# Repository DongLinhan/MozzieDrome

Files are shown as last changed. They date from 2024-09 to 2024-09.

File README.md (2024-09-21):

Details on the MozzieDrome circadian host-seeking assay

For construction, please refer to our preprint https://doi.org/10.1101/2024.09.19.613886

For additional construction details, see "MozzieDrome_construction"

For codes used in operating the MozzieDrome, see "MozzieDrome_operation"

For analysis of mosquito CO2 response, see "MozzieDrome_analysis"

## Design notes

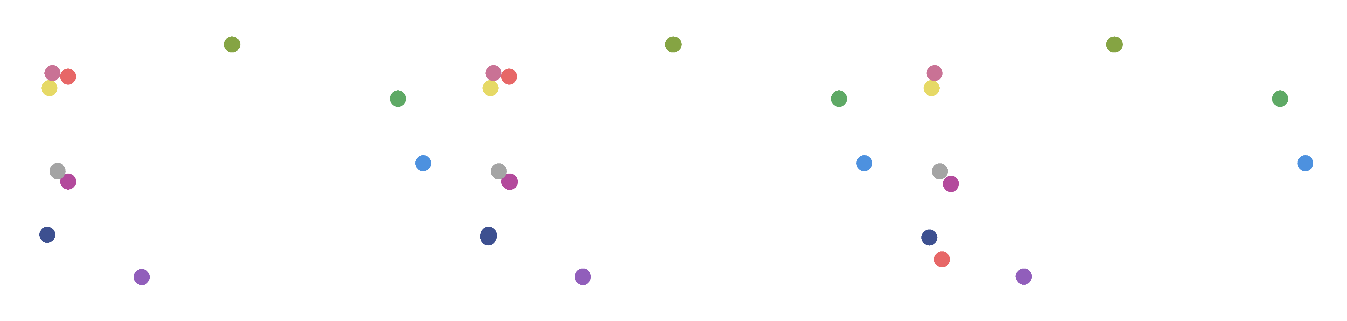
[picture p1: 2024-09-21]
MozzieDrome_analysis/Plotting_outputs/ZT18_new_representative_plots_solidcolors.png

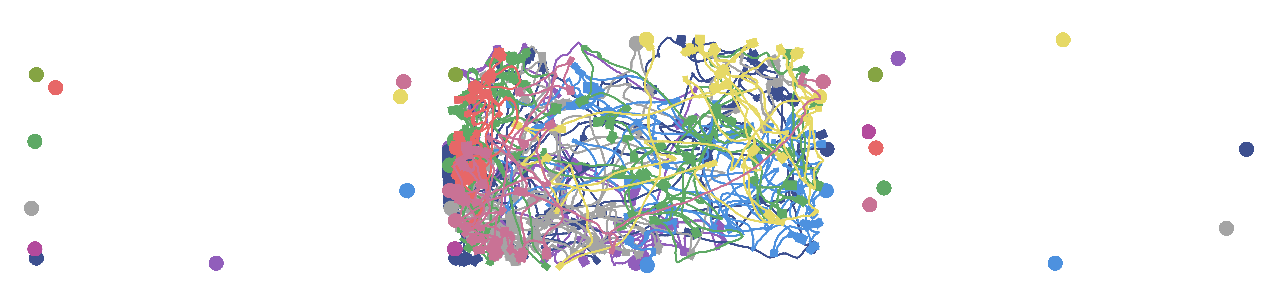
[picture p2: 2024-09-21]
MozzieDrome_analysis/Plotting_outputs/ZT6_new_representative_plots_solidcolors.png

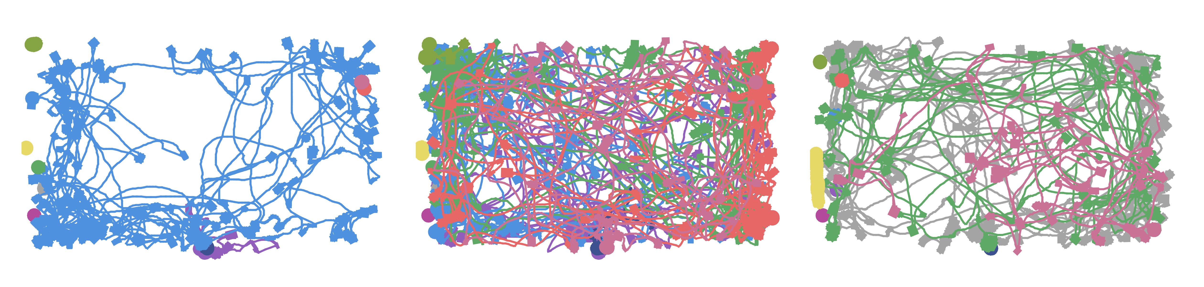
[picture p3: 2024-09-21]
MozzieDrome_analysis/Plotting_outputs/ZT12_new_representative_plots_solidcolors.png

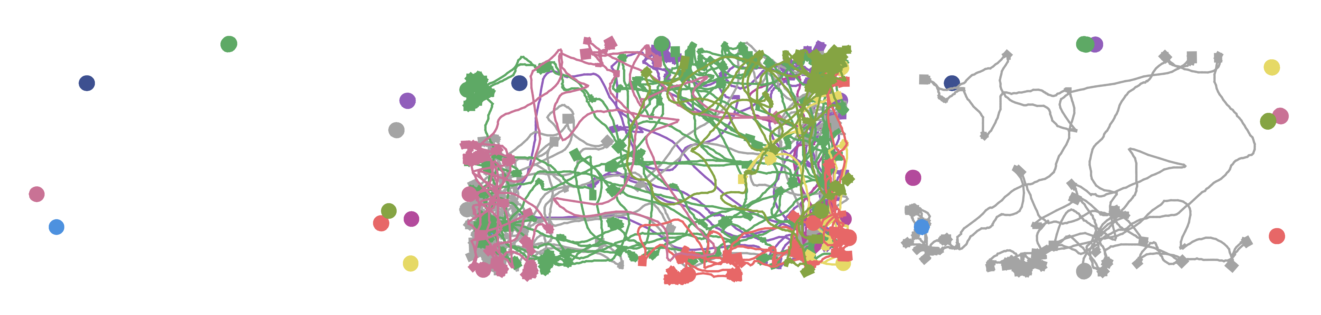
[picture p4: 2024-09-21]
MozzieDrome_analysis/Plotting_outputs/ZT0_new_representative_plots_solidcolors.png

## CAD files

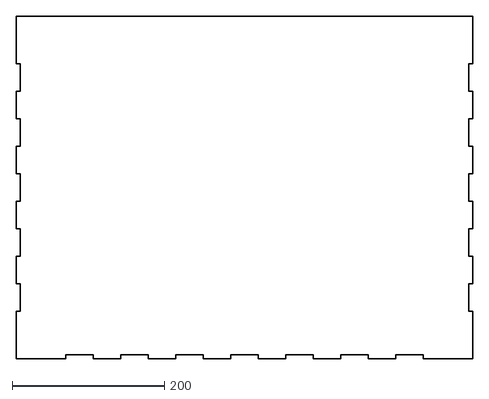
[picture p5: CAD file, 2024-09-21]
MozzieDrome_construction/Laser cutting files/Bottom-side.dxf
600.0 x 450.0

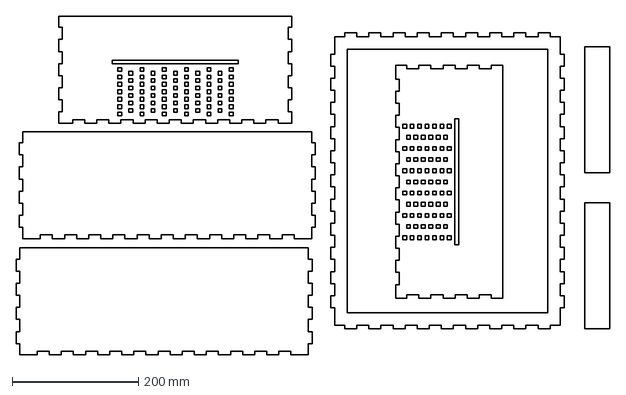
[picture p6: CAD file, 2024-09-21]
MozzieDrome_construction/Laser cutting files/side_light_box_final.dxf
942.5 x 537.6 mm

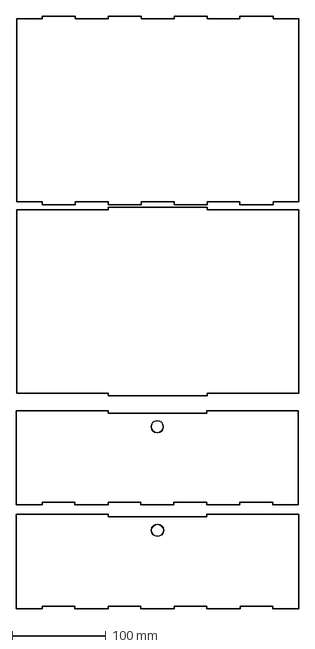
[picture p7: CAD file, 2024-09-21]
MozzieDrome_construction/Laser cutting files/arena_with_sugar_hole.dxf
300.8 x 630.4 mm

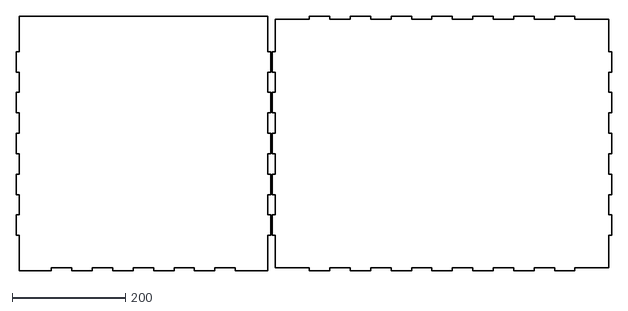
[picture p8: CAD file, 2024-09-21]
MozzieDrome_construction/Laser cutting files/Back-side.dxf
1053.0 x 450.0

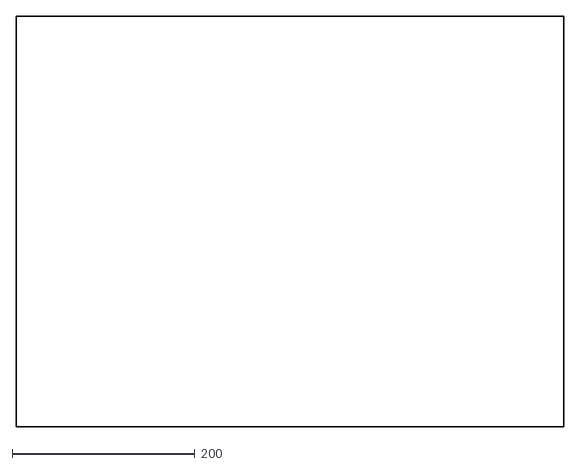
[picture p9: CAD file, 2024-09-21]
MozzieDrome_construction/Laser cutting files/door.dxf
600.0 x 450.0

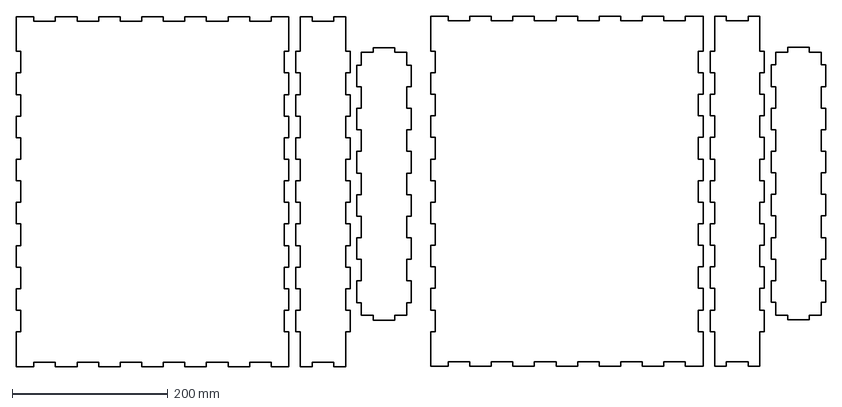
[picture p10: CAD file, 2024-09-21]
MozzieDrome_construction/Laser cutting files/back_light_box_final.dxf
1040.0 x 450.3 mm

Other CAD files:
MozzieDrome_construction/Laser cutting files/sugar_feeder_holder.dxf

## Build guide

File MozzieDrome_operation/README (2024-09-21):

The MozzieDrome assay builds on top of the Rampino system and therefore the folders are named as such for ease of operation. Briefly, the Matlab codes in the “Rampino folder establishes serial communication with an Arduino board equipped with coded in the “RampinoSVR” folder. Parameters can be found directly in the Matlab codes.

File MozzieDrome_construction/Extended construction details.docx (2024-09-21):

Extended construction details:

The MozzieDrome host-seeking assay features a circadian entrainment enclosure, a video-recording platform, a mosquito arena, with CO2 delivery components. Acrylic sheets for all custom-built components were processed with a laser cutter and/or a hand drill.

Circadian entrainment enclosure. The overall enclosure of the MozzieDrome is constructed with 1/4'’ black acrylic sheets. A 60 x 45 x 45 cm open box with ventilations is constructed with five finger edge joints with a 60 x 45 cm open face. The open box is assembled with acrylic cement. A 60 x 45 cm panel is installed with door hinges and latches secured with screw and nuts over holes created with a hand drill. Black foam tape was applied to the rims of the open box and them secured with duct tape. Black-out curtains were installed and used during experiments to completely cover the open door to ensure a tight, light-proof seal. Four rubber feet were sticked on the bottom of the box to provide elevation and soften vibration. The bottom of the box has ventilation holes that is then covered with an elevated black acrylic platform to ensure a complete dark environment. The pre-cut holes on top of the box were equipped with two USB cooling fans secured with hot glue, and then covered with an elevated platform and then another “cap”. The center of the top of the box has hole for camera placement. The lighting system of the MozzieDrome uses white LED strips covered with a 1/8’’ white translucent acrylic sheet to provide diffusion. The diffusion sheet has a pre-cut hole in the middle to allow camera to image through and holes around the edges to avoid blockage of air circulation. The white LED light is controlled together with the CO2 delivery system with a Matlab code to provide animals with LD (12 h light: 12 h dark, with 30 min transitions) and DD entrainments.

Video-recording platform. The video-recording platform features a camera mount that is installed on the camera hole on top of the overall enclosure and an IR light platform that provides illumination for videography. The camera mount was constructed with 1/4'’ black acrylic sheets with finger edge joints and a sliding front door. The bottom of the camera mount is equipped with black foam tape and the camera mount is installed on top of the overall enclosure with screw and nuts over holes created with a hand drill. An IR longpass filter is taped from the inside of the overall enclosure to block visible light from entering the enclosure and prevent visible light interfering with video acquisition. The IR light platform is constructed with 1/4’’ clear acrylic sheets. Backlight IR illumination was provided with a custom-built light box which was constructed with finger edge joints that was secured with acrylic glue. The light box was taped with reflective sheet and installed with strips of 840 nm IR light. On top of the light box, two sheets of Kimwipe were laid to provide diffusion. Surrounding the light box, we constructed a side IR light source with 1/4’’ clear acrylic sheets that was secured with acrylic cement. Mounted around this acrylic frame is 840 nm IR light covered with a white tape to provide diffusion. Both the side and the back lighting are powered with a 12V DC power source and turned on throughout experiments.

Mosquito arena. The mosquito arena was constructed with 1/8’’ clear acrylic sheets. A 10 x 20 x 30 cm rectangular tube (with 10 x 20 cm open faces) was constructed with finger edge joints and secured with acrylic cement. On the 10 x 30 cm sides, two pre-cut holes xx mm in diameter were designed to accommodate sugar feeders. The open faces were covered with mesh sheets that is secured on one 20 cm sides of the rectangular tube with hot glue. Mesh sheets have overhangs that allows them to be taped to the rectangular tubes on the adjacent sides. A stand for sugar feeder was constructed with 1/8’’ clear acrylic sheets and acrylic cement to sit on the rims of the side IR light source.

CO2 delivery system. The CO2 delivery system uses 1/4’’ OD tubings and 1/8’’ ID tubings. A solenoid valves were used to control the flow speed of CO2 by adjusting the duration of an on/off cycle according to readings from a flow meter. Custom mixed 10% CO2 was supplied to the solenoid valve, and the output side of the solenoid that is normally open is sealed with a short 1/4’’ OD tubing with a cap. The CO2 supply flows through the solenoid valve, a pressure-reducing chamber, a digital flowmeter, and a panel-mount flowmeter before entering the overall enclosure. Inside the overall enclosure, a T-spliter was used to divert the CO2 stream into two diffuser pads. The two diffuser pads were secured on the side IR light source.

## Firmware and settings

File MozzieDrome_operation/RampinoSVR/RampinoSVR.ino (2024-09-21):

#define REV "221216.1" 
/* 
 STILL IN DEVELOPMENT DC Motor section no tested yet
 REV 221216.1 adds special pinMode to set PWM frequency
 REV 221208.1 adds I2C support for TCA9548A MUX, STC31 Co2, SHTC3 Humidity, and Sfm3000 sensors, 
 REV 1.2 adds SPI for Adafruit DotStar LED strg Library
 REV 1.1 adds support for stepper limit switch polarity
 
 
 Rampino Server for MATLAB, Rick Hormigo, ZMBBI AIC Columbia university 2021                         
 state machine derived from 2012 arduinoio server by deGiampiero Campa for Matlab    
 This actual code supports current 2021 Arduino Mega board with Ramps 1.6 Plus boards 
 The communication arduinoio protocol has been modifified to minimize overhead
 acelerated to 250000 bauds, and extended to cover the modern stepper and DC motor drivers supported by Ramps  
 
 This server is meant to be used with the MATLAB rampino class. 
 The class is instantiated with a serial communitations port,
 what allows multiple instances as far each uses a separate port and Mega/Ramps combination
 Also it is possible to use a Mega board alone, if no extra electronics are requiered.
 This server can also be used along with other serial terminal softare that follows the protocol

Serial Protocol:
There is a state machine that process several states. The state s is calculated as: s=10*(val-48)
 Where val is what arrives to the serial port in decimal (or ASCII equivalent, a ex. a 88='X'):
 2 to 4 Bytes together are processed, First the mode (or command) where val is decimal 48 to 89,
 such as pinMode or AnalogRead, second the pin we are addresing where val is 99 to 166 depending on the command, 
 and third (if requiered) value for the pin that could be any decimal 0 to 255
 Then some commands can respond with a single byte or two for value.
 
At reset the state machine is s=-1 (idle) state while waits for a valid byte to arrive in the serial port. 
first byte that arrives is used to calculate next state s as s=10*(val-48) 
These are the possible command states:       
s=0  (val=48 or '0')is pinMode
s=10 (val=49 or '1')is digitaRead
s=20 (val=50 or '2')is digitalWrite;  
s=30 (val=51 or '3')is analogRead
s=40 (val=52 or '4')is analogWrite 
s=50 (val=53 or '5')is servoStatus
s=60 (val=54 or '6')is servoAttach and servoDetach 
s=70 (val=55 or '7')is servoRead
s=80 (val=56 or '8')is servoWrite
s=90 (val=57 or '9')is server type. This is Rampino=82 (Ascii 'R')
s=100(val=58 or ':')is tone  
s=110(val=59 or ';')is DCMotorAttach and DCMotorDetach
s=120(val=60 or '<')is DCMotorStatus
s=130(val=61 or '=')is DCMotorVelocity
s=170(val=65 or 'A')is stepperAttach and stepperDetach
s=180(val=66 or 'B')is stepperStatus
s=190(val=67 or 'C')is stepperSpeed
s=200(val=68 or 'D')is stepperStep
s=210(val=69 or 'E')is encoderAttach
s=220(val=70 or 'F')is encoderDetach
s=230(val=71 or 'G')is encoderRead
s=240(val=72 or 'H')is encoderReset
s=250(val=73 or 'I')is encoderDebounce
s=270(val=75 or 'K')is SPI serialLEDs (DotStar)
s=290(val=77 or 'M')is I2C Mux and Multiple sensors 
s=340(val=82 or 'R')is analogReference
s=400(val=88 or 'X')is roundTrip

Next (for most commands) the pin value is read as val=99 to 166 or ascii 'c' to 'ª'
to what is subtacted 97 to calculate the pin=2 to 69 (Mega pins)

Depending on the command there can be other additional states involving byte values need for execution
(see below individual commands)

A simple example to set pin 13 in output mode... 48-110-49 (in decimal sending) or "0n1" no quotations nor CR LF values used (ASCII string).

Mega harware resources used by rampino:
Serial0: Protocol interface
Timer0: Timing: delay(), millis, and micros(). AnalogWrite at pins 4 and 23 (Mega)
Timer1: 16bit used by Servo lib pins 2 to 11. AnalogWrite at pins 11 and 12 (Mega)
Timer2: DC Motor PWM at Any Pin library (DCM_PWM_AP). AnalogWrite at pins 9 and 10 (Mega)
Timer3: Tones (3rd instance) AnalogWrite at pins 2, 3, and 5 (Mega)
Timer4: Tones (2nd instance) AnalogWrite at pins 6, 7, and 8 (Mega) 
Timer5: Tones (1st instance) AnalogWrite at pins 44, 45, and 46 (Mega) 
*/

//Custom Libs
#include "rampino.h"
#include "BasicStepperDriver.h"
#include "DCM_PWM_AP.h"
#include "Tone.h"
#include "Servo.h"
//SPI
#include <SPI.h>    
#include <Adafruit_DotStar.h>
//I2C   
#include <Wire.h>
#include <SparkFun_STC3x_Arduino_Library.h> 
#include <SparkFun_SHTC3.h> 
#include <PWFusion_TCA9548A.h>
#include <SensirionI2CSfm3000.h>



//Dot Start Support (SPI only )
#define DATAPIN    51   
#define CLOCKPIN   52
#define NUMPIXELS 64 // Default Number of LEDs in strip
//Dot Start Commands (operations)
#define ENPIXS  49 //ascii '1', Free SPI pins
#define SHOW 50 //ascii '2',  Transmit set info to light LEDs
#define CLEAR 51 //ascii '3', Set all LEDs off
#define SETNUMPIXELS 52 //ascii '4', Set new Number of LEDs
#define SETBRIGHT 53 //ascii '5', Set LEDs bright 
#define SETPIX 60 //ascii '<', Set Pixel color
#define SETPIXS 61 //ascii '=', Set all LEDs off
Adafruit_DotStar strip(NUMPIXELS, DATAPIN, CLOCKPIN, DOTSTAR_BGR);


//I2C Sensors
//Operations
#define TCA9548_EN  1//Switch Enable with I2C address x70 is default
#define TCA9548_SEL 2//Swich Port
#define STC3X_EN    10//CO2 Sensor Enable (uses SHTC3 for compensation)  
#define STC3X_CAL   11//CO2 Sensor set actual Gas Concentration in porcentage as reference for Calibration
#define STC3X_STMP  12//CO2 Sensor set current temperature for compensation
#define STC3X_SHUM  13//CO2 Sensor set current humidity for compensation
#define STC3X_SPRE  14//CO2 Sensor set current or known enviroment Pressure for compensation
#define STC3X_RDT   15//CO2 Sensor Reads CO2 Temperature
#define STC3X_RDG   16//CO2 Sensor Reads CO2 Gas Concentration in porcentage 
#define SHTC3_EN    20//Humidity Sensor Enable 
#define SHTC3_RDH   21//Humidity Sensor Reads Humidity Percentage
#define SHTC3_RDT   22//Humidity Sensor Reads Temperature
#define SFM3000_EN  30//GAS FLOW Sensor Enable 
#define SFM3000_RD  31//GAS FLOW Sensor Reads Flow in lpm
TCA9548A tca9548aMux;
STC3x stc3xSensor;
SHTC3 shtc3Sensor;
SensirionI2CSfm3000 sfm3000Sensor;


// define internal analog reference for Arduino Mega
#define INTERNAL INTERNAL1V1

// Encoder structure                                  
typedef struct { int pinA; int pinB; int pos; int del;} Encoder;    
volatile Encoder Enc[3] = {{0,0,0,0}, {0,0,0,0}, {0,0,0,0}};

// Servos                                       
Servo servo[12]; //Mega 48 max (12, 10 used in rampino) # of servos array instantiate

//DC Motors
DCM_PWM_AP dcMotor[5] = {{X_STEP, X_DIR, X_ENABLE},   //DC Motor class array instantiate. 
                        {Y_STEP, Y_DIR, Y_ENABLE}, 
                        {Z_STEP, Z_DIR, Z_ENABLE}, 
                        {E0_STEP, E0_DIR, E0_ENABLE}, 
                        {E1_STEP, E1_DIR, E1_ENABLE}}; 
byte dcAttached[]={0,0,0,0,0};    //Flags for DC motors atttached status: 0-dettached, 1-Attached, 2-Attached with direction flip 

//Stepper Motors
BasicStepperDriver sMotor[5]={{200, X_DIR, X_STEP, X_ENABLE},   //Stepper class array instantiate. 
                              {200, Y_DIR, Y_STEP, Y_ENABLE},   //Pins are activated outs on begin (attach)
                              {200, Z_DIR, Z_STEP, Z_ENABLE},   //de-activated as inputs on (detach)
                              {200, E0_DIR, E0_STEP, E0_ENABLE},//so could be overrided for diferent use.
                              {200, E1_DIR, E1_STEP, E1_ENABLE}};
uint8_t smAttached[]={0,0,0,0,0};    //Flags for stepper motors atttached status: 0-dettached, 1-Attached Software, 2-Attached Hardware 
uint8_t smAutoD[]={0,0,0,0,0};       //Auto disable (release motor) time in ms, 0 is no autodisable 
bool smAutoDSet[]={0,0,0,0,0};       //Auto disable (release motor) time is set 
uint8_t smLimitOn[]={0,0,0,0,0};   //used for fast homing limit function, 2-69 pin pending for homing (active low), 0 for homing off/done
//bool limitDetect[]={0,0,0,0,0};  //Limit switch asserted but still pending delayed disable.          
uint8_t microstepMode[]={1,2,4,8,16,32,32,16};  //A4988 -> {1,2,4,8,-,-,-,16}  DRV8825 {1,2,4,8,16,32,32,-}   
#define RELEASE_DELAY  50 //mS to release
bool limActive=LOW; //Assert Polarity of limit switch for motors 
// Microstepping pins
byte MODE_MS3[]={A9,40,42,A11,A12};
#define MODE_MS1      MOSI
#define MODE_MS2      SCK
#define N_RESET_SM    MISO 
//Stepper Operations(no pins)
#define DISABLE       48 //ascii '0'
#define STOP          49 //ascii '1'
#define BRAKING       50 //ascii '2'
#define ENABLE        56 //ascii '8' 
#define CHANGE_RUN    57 //ascii '9'
#define ENABLE_AD     58 //ascii ':'
#define CHANGE_RUN_AD 59 //ascii ';'




// Steppers Notes on microsepping modes, using Library  BasicStepperDriver by Laurentiu Badea: 
//Mod0 at 240->237rpm (optic measured) gives 790.6Hz*60 47436/mt /200= 237rpm --400 marginal max that measures 391 rpm max
//Mod1 at 240->235rpm gives 1550Hz *60 = 93000/mt /400 steps=232rpm
//Mod2 at 240->230rpm. gives 3068Hz*60= 184080/mt  /800 = 230.1 rpm
//Mod3 at 240->220rpm  gives 5860Hz *60= 351600/mt /1600 =220 rpm --400 marginal max that measures 340 rpm max
//Mod4 at 240->199.5rpm  gives 10620Hz *60= 637200/mt /3200 =199.1 rpm --500 marginal max that measures 358 rpm max
//Mod5 at 240->180 rpm  gives 19100Hz *60= 1146000/mt /6400 =179 rpm --500 marginal max that measures 184 rpm max
//NOTE: This libray doesn't block when moving, yet the main loop is blocked by the length of a step,
// and a step could be as short as 20uS (at 255RPM and X32 microstepping), but as long as 300mS for full steps at 1 RPM  

//TONES-----Max 4 posible tones simultaneously, implemente  3 pins only for DC motor compatibility.  --MEGA only. 
Tone tonePin[3]; // Simultaneus tones may easily conflict with other hardware use. This implimentation limits to timers 3, 4, and 5
uint8_t tonePinMap[]={0,0,0}; //Pins asigned to TonePin instances
//NOTE: The Tone.h lib currently can generate up to 65535Hz, but over 323767Hz the duration parameter must be 0, then control with stop
//NOTE: Frequencies can generate an undesired random mix if a frequency is time overlapped with another frequency on the same pin.
//Only 3 instances (one by timer) of the class are allowed in this Rampino implementation, the 4th will replace the first automatically.  
//Limitation: if used 4 pins, the 4th created instance (that corresponds to timer 2) can't handle frequency under 32Hz
 
void setup() {
  // initialize serial 
 // Serial2.begin(115200); //R&D Debug
 // Serial2.println("---START DEBUG SESSION---");                                   
  Serial.begin(115200); //up to 250000 Bauds that is multiple of 16M and available at Arduino IDE Monitor
  Serial.print(REV);  //Initial Charecter to indicate port has opened (This is important with slow drivers that take long to open the serial)
                       //I found that in slow computers the serial print/write may happen before the serial is efectivelly open, leading to serial block  
#if 0  //R&D DCM testing
  for (uint8_t i = 0; i < 5; i++)
  {
    dcMotor[i].begin();  //attach pins
  }
  dcMotor[4].setSpeed(1);    
  while(1){ 
    for(int8_t dc=100;dc>=0;dc--){
      for (uint8_t i=0; i < 4; i++){
          dcMotor[i].setVelocity(dc);
      }
      delay(20);
    }
  }
#endif

}

/*******************************************************************************************************************/
void loop() {
  
  static int  s   = -1;    // state     
  static uint8_t mt; //motor sequence in main loop                     
  static int  pin = 13;    // generic pin number             
  static int  enc = 0;     // generic encoder number         
  static int  motor = 0;  // generic motor number         
  static long sdgv =  0;  // Long serial digital value
  static uint8_t sdgv8;   // 8 bit serial digital value
  static uint16_t sdgv16;   // 16 bit serial digital value
  static unsigned int frequency = 0;  //Tone frequency in Hz, 0 to stop tone 
  static unsigned int duration = 0;   //Tone Duration in mS, 0 means keep playing until stop by frequency 0.
  static uint8_t toneInstCnt = 2; //Tone Pin Instance counter, 0 to 2, if more is requested, get overlapped to 0
  static int8_t toneInstIdx = -1;//Tone Pin Instance counter Index lo locate if pin is attached
  static uint8_t red, green, blue; // 8 bit serial bytes 

  union {
    float f; // float serial digital value
    byte a[4]; // float serial digital value array access
    uint32_t i; //32 bit integer representation (needed to create special single NaN) 
  }static sTmp;
  union {
    float f; // float serial digital value
    byte a[4]; //// float serial digital value array access
  }static scalingFactor;
  union {
    float f; // float serial digital value
    byte a[4]; //// float serial digital value array access
  }static offset;

  static bool tca9548a_EN=false;

  static BasicStepperDriver::Profile profile;  //Profile parameters structure to pass to the class
  
  bool err = false;        //generic bool answer
  int  val =  0;           // generic value read from serial 
  int  agv =  0;           // generic analog value           
  long dgv =  0;           // generic digital value          

          
  //Wait in external loop until somenthing arrives via serial
  if (Serial.available() >0) {
    val = Serial.read();
    // This is the state machine that process the value.
    // Itnitially is Idle (s=-1) where it checks for new arriving values 
    // to move to the next state that is the command to run  
    switch (s) {
      case -2:  //We should not be here! Protocol validation error, wait for extra data and clear. 
        delay(10);
        while (Serial.read() != -1); //clear trouble at buffer (-1 means empty) and go idle
        s=-1;
        break;
      case -1:  //idle so check comming value 1st Byte as a command to determine next state (see command table above)
        if (val>47 && val<90) {
          s=10*(val-48); //calculate next state based in first recived byte
          //Serial2.print("Sate -1 Next "); Serial2.print(s); Serial2.print(" "); Serial2.println(val); 
        }
        //validate further results. If out of range, reset state to idle
        if ((s>130 && s<170) || (s>290 && s!=340 && s!=400))
          s=-2;
        break; 
        
      case 0: //process pinMode() the second received byte indicates the pin 
              //byte value from ascii 'c'=99, pin 2, to ascii 'ª'=166, pin 69  
        if (val>98 && val<167) {
          pin=val-97; //calculate pin       
          s=1;        // next we will need to know status for this pin in, out, or pull */
        } 
        else {
          s=-2; //validation failed so reset
        }
        break;
      case 1: //process pinMode() third byte to find pin status to be  input, output, or pullUp
              //values are defined as: ascii '0'=48 for input, ascii '1'=49 for output, and ascii '2'=50 for pullUp
              //51 to 55 for PWM Frequencies  
        if (val>47 && val<56)  {
          // set pin mode
          switch(val){
            case 50:
              pinMode(pin,INPUT_PULLUP);
              break;
            case 49:
              pinMode(pin,OUTPUT);
              break;
            case 51 ... 55:  //Special mode for analog write with alternative frequencies (see setPwmFrequencyMEGA below)
              setPwmFrequencyMEGA(pin,val);
              break;             
            default:
              pinMode(pin,INPUT);         
          }   
          s=-1;  //pinMode() is complete, so reset state
        }
        else
          s=-2; //Validation trouble
        break;

      case 10: //digitalRead() the second received byte indicates the pin 
              //byte value from ascii 'c'=99, pin 2, to ascii 'ª'=166, pin 69  
        if (val>98 && val<167) {
          pin=val-97;                //calculate pin    
          dgv=digitalRead(pin);      // read and return value via serial 
          Serial.write(dgv+48);   //This returns 48 ascii '0' or 49 ascii '1' 
          s=-1;  //digitalRead() is complete, so reset state     
        }
        else
          s=-2; //Validation trouble
        break; 

      case 20: //digitalWrite() the second received byte indicates the pin 
               //byte value from ascii 'c'=99, pin 2, to ascii 'ª'=166, pin 69  
        if (val>98 && val<167) {
          pin=val-97;   //calculate pin  
          s=21;         //next we will need to know from serial if set 0 or 1 
        } 
        else {
          s=-2; //if validation fails, reset
        }
        break;
      case 21:  //digitalWrite() the third received byte indicates the value to set:
                // ascii '0'=48 for 0, and  ascii '1'=49 for 1 
        if (val>47 && val<50) {
          dgv=val-48;                /* calculate value        */
          digitalWrite(pin,dgv);     /* perform Digital Output */
          s=-1;  //digitalWrite() complete
        }
        else
          s=-2; //Validation trouble
        break; 

      case 30://analogRead() the second received byte indicates the pin 
              //byte value from ascii 'a'=97, pin 0, to ascii 'p'=112, pin 15  
        if (val>96 && val<113) {
          pin=val-97;           //calculate pin    
          agv=analogRead(pin);  //read and return via serial
          Serial.write(agv & 0xFF); //send binary LSB  
          Serial.write(agv>>8);     //send binary MSB
          s=-1; //analogRead() complete
        }
        else
          s=-2; //Validation trouble
        
        break;

      case 40://analogWrite() the second received byte indicates the pin 
              //byte value from ascii 'c'=99, pin 2, to ascii 'ª'=166, pin 69  
        if (val>98 && val<167) {
          pin=val-97;   // calculate pin       
          s=41;         // next find byte value from serial to be written
        }
        else {
          s=-2; //if validation fails, reset
        }
        break; 
      case 41: //analogWrite() the third received byte indicates the value to write
        analogWrite(pin,val);
        s=-1;  //analogWrite() complete
        break;                 

      case 50: //servoStatus() the second received byte indicates the pin
               //byte value from ascii 'c'=99, pin 2, to ascii 'l'= 108, pin 11
        if (val>98 && val<109) {
          pin=val-97;                 // calculate pin
          dgv=servo[pin].attached();  //read if attached and send answer as 0 or 1
          Serial.write(dgv);
          s=-1;  //Competed, so reset    
        }
        else
          s=-2; //Validation trouble
        break; 
         
      case 60://servoAttach()/servoDetach() the second received byte indicates the pin
              //byte value from ascii 'c'=99, pin 2, to ascii 'l'= 108, pin 11 
        if (val>98 && val<109) {
          pin=val-97;    //calculate pin and set next state to set if Attach or Detach    
          s=61;   
        } 
        else {
          s=-2; //validation failed
        }
        break;
      case 61://servoAttach()/servoDetach() the third received byte indicates the value to set:
              // ascii '0'=48 is Detach, and  ascii '1'=49 is Detach 
        if (val>47 && val<50) {
          dgv=val-48;   //convert ascii '0' or '1' to number 0 or  1, false or true.
          if (dgv)
            servo[pin].attach(pin);    
          else
            servo[pin].detach();     
          s=-1;  // Completed, so reset
        }
        else
          s=-2; //Validation trouble
        break;

      case 70://servoRead() the second received byte indicates the pin
              //byte value from ascii 'c'=99, pin 2, to ascii 'l'= 108, pin 11
        if (val>98 && val<109) {
          pin=val-97;     //calculate pin   
          agv=servo[pin].read();// read servo and send position back to client
  	      Serial.write(agv);
          s=-1;  // Completed, so reset  
        }
        else
          s=-2; //Validation trouble
        break; 
        
      case 80://servoWrite() the second received byte indicates the pin
              //byte value from ascii 'c'=99, pin 2, to ascii 'l'= 108, pin 11
        if (val>98 && val<109) {
          pin=val-97;   //calculate pin and set next state to set the position
          s=81; 
        }
        else {
          s=-2; //validation failed
        }
        break;  
      case 81://servoWrite() the third received byte indicates the value to write 
        servo[pin].write(val);                
        s=-1;  // Completed, so reset
        break;        

      case 90: //rampino() constructor calling for validation for the this server type and been active.
               //client sends 57 or ascii '9' twice, this server answers 82 or ascii 'R'for rampino type
        //Serial2.print("Sate 90 "); Serial2.println(val); 
        if (val==57) { 
          Serial.write('R');  //value 82
          s=-1;  // Completed, so reset
        }
        else
          s=-2; //Validation trouble
        break;     

      case 100://tone() the second received byte indicates the pin
              //byte value from ascii 'c'=99, pin 2, to ascii 'ª'=166, pin 69  
        if (val>98 && val<167) {
          pin=val-97;   //calculate pin 
          //Keep map of pins used to tone instances (using 3 tones on pin simultaneously)
          toneInstIdx=isPinAttached(tonePinMap,sizeof(tonePinMap),pin);
          if (toneInstIdx==-1){ //pin no attached, attach (tonePinMap) and init object (tonePin)
            if (++toneInstCnt>2) toneInstCnt=0;   //Roll over 0, 1, 2, 0...      
            toneInstIdx=toneInstCnt; 
            tonePinMap[toneInstIdx]=pin;  
            tonePin[toneInstIdx].begin(pin);
          }
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

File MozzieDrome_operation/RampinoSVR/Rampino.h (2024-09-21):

/* Arduino Mega with RAMPS v1.6 Plus for AIC ZMBBI
 * Columbia University 2021 */

//
// Servos
//
#define SERVO1                        11
#define SERVO2                         6
#define SERVO3                         5
#define SERVO4                         4

//
// Limit Switches
//
#define X_MIN                          3
#define X_MAX                          2
#define Y_MIN                         14
#define Y_MAX                         15
#define Z_MIN                         18
#define Z_MAX                         19

//
// Steppers
//
#define X_STEP                        54
#define X_DIR                         55
#define X_ENABLE                      38

#define Y_STEP                        60
#define Y_DIR                         61
#define Y_ENABLE                      56

#define Z_STEP                        46
#define Z_DIR                         48
#define Z_ENABLE                      62

#define E0_STEP                       26
#define E0_DIR                        28
#define E0_ENABLE                     24

#define E1_STEP                       36
#define E1_DIR                        34
#define E1_ENABLE                     30

//
// Analog Sensors
//
#define TEMP_0                        A13 
#define TEMP_1                        A14  
#define TEMP_2                        A15  

//
// Solenoids
//
#define RAMPS_D8                        8   //BIG J28
#define RAMPS_D9                        9
#define RAMPS_D10                      10

//
// Misc. Functions
//

#define LED_D5                         13
#define PS_ON                          12

//AUX-1
#define AUX1_S3                       TX0   //1
#define AUX1_S4                       RX0   //0
#define AUX1_A3                       A5
#define AUX1_A4                       A5

//AUX-2
#define AUX2_3                        A5
#define AUX2_4                        A9
#define AUX2_5                        A10
#define AUX2_6                        40
#define AUX2_7                        44
#define AUX2_8                        42
#define AUX2_9                        A12
#define AUX2_10                       A11

//AUX-3 / SPI
#define AUX3_2                        49
#define AUX3_3                        MISO  //50
#define AUX3_4                        MOSI  //51
#define AUX3_5                        SCK   //52
#define AUX3_6                        SS    //53

//AUX-4
#define AUX4_3                        32
#define AUX4_4                        47
#define AUX4_5                        45
#define AUX4_6                        43
#define AUX4_7                        41
#define AUX4_8                        39
#define AUX4_9                        37
#define AUX4_10                       35
#define AUX4_11                       33
#define AUX4_12                       31
#define AUX4_13                       29
#define AUX4_14                       27
#define AUX4_15                       25
#define AUX4_16                       23
#define AUX4_17                       17
#define AUX4_18                       16

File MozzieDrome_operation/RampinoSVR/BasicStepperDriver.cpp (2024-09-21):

/*
 * Generic Stepper Motor Driver Driver
 * Indexer mode only.

 * Copyright (C)2015-2019 Laurentiu Badea
 *
 * This file may be redistributed under the terms of the MIT license.
 * A copy of this license has been included with this distribution in the file LICENSE.
 *
 * Linear speed profile calculations based on
 * - Generating stepper-motor speed profiles in real time - David Austin, 2004
 * - Atmel AVR446: Linear speed control of stepper motor, 2006
 */
#include "BasicStepperDriver.h"

/*
 * Basic connection: only DIR, STEP are connected.
 * Microstepping controls should be hardwired.
 */
BasicStepperDriver::BasicStepperDriver(short steps, short dir_pin, short step_pin)
:BasicStepperDriver(steps, dir_pin, step_pin, PIN_UNCONNECTED)
{
}

BasicStepperDriver::BasicStepperDriver(short steps, short dir_pin, short step_pin, short enable_pin)
:motor_steps(steps), dir_pin(dir_pin), step_pin(step_pin), enable_pin(enable_pin)
{
	steps_to_cruise = 0;
	steps_remaining = 0;
	dir_state = 0;
	steps_to_brake = 0;
	step_pulse = 0;
    cruise_step_pulse = 0;
	rest = 0;
	step_count = 0;
}

/*
 * Initialize pins, calculate timings etc
 */
void BasicStepperDriver::begin(float rpm, short microsteps){
    pinMode(dir_pin, OUTPUT);
    digitalWrite(dir_pin, HIGH);

    pinMode(step_pin, OUTPUT);
    digitalWrite(step_pin, LOW);

    if IS_CONNECTED(enable_pin){
        pinMode(enable_pin, OUTPUT);
        disable();
    }

    this->rpm = rpm;
    setMicrostep(microsteps);

    enable();
}

/*
 * Set target motor RPM (1-200 is a reasonable range)
 */
void BasicStepperDriver::setRPM(float rpm){
    if (this->rpm == 0){        // begin() has not been called (old 1.0 code)
        begin(rpm, microsteps);
    }
    this->rpm = rpm;
}

/*
 * Set stepping mode (1:microsteps)
 * Allowed ranges for BasicStepperDriver are 1:1 to 1:128
 */
short BasicStepperDriver::setMicrostep(short microsteps){
    for (short ms=1; ms <= getMaxMicrostep(); ms<<=1){
        if (microsteps == ms){
            this->microsteps = microsteps;
            break;
        }
    }
    return this->microsteps;
}

/*
 * Set speed profile - CONSTANT_SPEED, LINEAR_SPEED (accelerated)
 * accel and decel are given in [full steps/s^2]
 */
void BasicStepperDriver::setSpeedProfile(Mode mode, short accel, short decel){
    profile.mode = mode;
    profile.accel = accel;
    profile.decel = decel;
}
void BasicStepperDriver::setSpeedProfile(struct Profile profile){
    this->profile = profile;
}

/*
 * Move the motor a given number of steps.
 * positive to move forward, negative to reverse
 */
void BasicStepperDriver::move(long steps){
    startMove(steps);
    while (nextAction());
}
/*
 * Move the motor a given number of degrees (1-360)
 */
void BasicStepperDriver::rotate(long deg){
    move(calcStepsForRotation(deg));
}
/*
 * Move the motor with sub-degree precision.
 * Note that using this function even once will add 1K to your program size
 * due to inclusion of float support.
 */
void BasicStepperDriver::rotate(double deg){
    move(calcStepsForRotation(deg));
}

/*
 * Set up a new move (calculate and save the parameters)
 */
void BasicStepperDriver::startMove(long steps, long time){
    float speed;
    // set up new move
    dir_state = (steps >= 0) ? HIGH : LOW;
    last_action_end = 0;
    steps_remaining = labs(steps);
    step_count = 0;
    rest = 0;
    switch (profile.mode){
    case LINEAR_SPEED:
        // speed is in [steps/s]
        speed = rpm * motor_steps / 60;
        if (time > 0){
            // Calculate a new speed to finish in the time requested
            float t = time / (1e+6);                  // convert to seconds
            float d = steps_remaining / microsteps;   // convert to full steps
            float a2 = 1.0 / profile.accel + 1.0 / profile.decel;
            float sqrt_candidate = t*t - 2 * a2 * d;  // in √b^2-4ac
            if (sqrt_candidate >= 0){
                speed = min(speed, (t - (float)sqrt(sqrt_candidate)) / a2);
            };
        }
        // how many microsteps from 0 to target speed
        steps_to_cruise = microsteps * (speed * speed / (2 * profile.accel));
        // how many microsteps are needed from cruise speed to a full stop
        steps_to_brake = steps_to_cruise * profile.accel / profile.decel;
        if (steps_remaining < steps_to_cruise + steps_to_brake){
            // cannot reach max speed, will need to brake early
            steps_to_cruise = steps_remaining * profile.decel / (profile.accel + profile.decel);
            steps_to_brake = steps_remaining - steps_to_cruise;
        }
        // Initial pulse (c0) including error correction factor 0.676 [us]
        step_pulse = (1e+6)*0.676*sqrt(2.0f/profile.accel/microsteps);
        // Save cruise timing since we will no longer have the calculated target speed later
        cruise_step_pulse = 1e+6 / speed / microsteps; 
        
        break;

    case CONSTANT_SPEED:
    default:
        steps_to_cruise = 0;
        steps_to_brake = 0;
        step_pulse = cruise_step_pulse = STEP_PULSE(motor_steps, microsteps, rpm);
        if (time > steps_remaining * step_pulse){
            step_pulse = (float)time / steps_remaining;
        }
    }
}
/*
 * Alter a running move by adding/removing steps
 * FIXME: This is a naive implementation and it only works well in CRUISING state
 */
void BasicStepperDriver::alterMove(long steps){
    switch (getCurrentState()){
    case ACCELERATING: // this also works but will keep the original speed target
    case CRUISING:
        if (steps >= 0){
            steps_remaining += steps;
        } else {
            steps_remaining = max(steps_to_brake, steps_remaining+steps);
        };
        break;
    case DECELERATING:
        // would need to start accelerating again -- NOT IMPLEMENTED
        break;
    case STOPPED:
        startMove(steps);
        break;
    }
}
/*
 * Brake early.
 */
void BasicStepperDriver::startBrake(void){
    switch (getCurrentState()){
    case CRUISING:  // this applies to both CONSTANT_SPEED and LINEAR_SPEED modes
        steps_remaining = steps_to_brake;
        break;

    case ACCELERATING:
        steps_remaining = step_count * profile.accel / profile.decel;
        break;

    default:
        break; // nothing to do if already stopped or braking
    }
}
/*
 * Stop movement immediately and return remaining steps.
 */
long BasicStepperDriver::stop(void){
    long retval = steps_remaining;
    steps_remaining = 0;
    return retval;
}
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
